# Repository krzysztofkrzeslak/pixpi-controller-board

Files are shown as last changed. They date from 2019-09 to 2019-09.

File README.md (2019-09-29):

### PiXPi controller board source

This are sources for PiXPi controller board

Morea bout project on: https://hackaday.io/project/166730-pixpi-dslr-camera-controller

<p align="center">
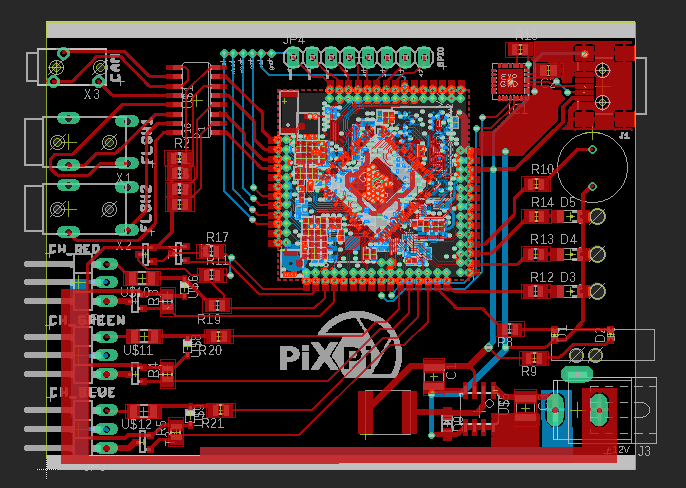
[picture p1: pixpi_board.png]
  
</p>

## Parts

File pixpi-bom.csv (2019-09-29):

Part | Value | Device | Package | Model
C1 | 47u | CC1210 | C1210
C2 | 100n | C | C0805
C3 | 22u | CC1210 | C1210
D1 | Blue | LEDCHIPLED_0603 | CHIPLED_0603 | FYLS-0603UBC
D2 | Green | LEDCHIPLED_0603 | CHIPLED_0603 | CL-197HG5-CF
D3 | Blue | LEDCHIPLED_1206 | CHIPLED_1206 | FYLS-1206UBC
D4 | Green | LEDCHIPLED_1206 | CHIPLED_1206 | FYLS-1206PGC
D5 | Red | LEDCHIPLED_1206 | CHIPLED_1206 | FYLS-1206URC
D9 |  | DIODE-SOD323-W | SOD323-W | BAS3010A03WE6327HTSA1
IC1 | CP2101 | CP2101 | MLP28
J1 | USB_MINI-B_SMT | USB_MINI-B_SMT | USB-MINIB
J3 |  | JACK-PLUG0 | SPC4077 | NINIGI PC-GK2.1
JP1 |  | PINHD-1X3/90 | 1X03/90 | FCI 76382-303LF
JP2 |  | PINHD-1X3/90 | 1X03/90 | FCI 76382-303LF
JP3 |  | PINHD-1X3/90 | 1X03/90 | FCI 76382-303LF
JP4 |  | PINHD-1X8 | 1X08
R1 | 470R | R-EU_R0805 | R0805
R2 | 470R | R-EU_R0805 | R0805
R3 | 100k | R-EU_R0805 | R0805
R4 | 100k | R-EU_R0805 | R0805
R5 | 100k | R-EU_R0805 | R0805
R6 | 470R | R-EU_R0805 | R0805
R7 | 470R | R-EU_R0805 | R0805
R8 | 10k | R-EU_R0805 | R0805
R9 | 10k | R-EU_R0805 | R0805
R10 | 10R | R-EU_R0805 | R0805
R11 | 4.7k | R-EU_R0805 | R0805
R12 | 470R | R-EU_R0805 | R0805
R13 | 1k | R-EU_R0805 | R0805
R14 | 470R | R-EU_R0805 | R0805
R15 | 4.7k | R-EU_R0805 | R0805
R17 | 100k | R-EU_R0805 | R0805
R19 | 220R | R-EU_R0805 | R0805
R20 | 220R | R-EU_R0805 | R0805
R21 | 220R | R-EU_R0805 | R0805
T1 |  | NMOSSOT23 | SOT-23 | TSM2312CX
T2 |  | NMOSSOT23 | SOT-23 | TSM2312CX
T3 |  | NMOSSOT23 | SOT-23 | TSM2312CX
T4 |  | NMOSSOT23 | SOT-23 | 2N7002
T5 |  | NMOSSOT23 | SOT-23 | 2N7002
U$1 | QUAD_OPTOCOUPLER | QUAD_OPTOCOUPLER | SO16 | TCMT4100
U$2 | VOCORE2 | VOCORE2 | VOCORE2
U$3 | LD-BZEG-0905 | LD-BZEG-0905 | LD-BZEG-0905 | LD-BZEG-0905
U$4 | 1X6 | 1X6 | 1X6
U$5 | AP1509 | AP1509 | SOP08
U$6 | BZX84J | BZX84J | SOD323_ST | BZX84J-B3V6.115
U$7 | 33uH | DJNR6028 | DJNR6028
U$8 | BZX84J | BZX84J | SOD323_ST | BZX84J-B3V6.115
U$9 | BZX84J | BZX84J | SOD323_ST | BZX84J-B3V6.115
U$10 | SN005 | SN005 | R1206 | ECE SN005-60
U$11 | SN005 | SN005 | R1206 | ECE SN005-60
U$12 | SN005 | SN005 | R1206 | ECE SN005-60
X1 | 1503_08 | 1503_08 | 1503_08
X2 | 1503_08 | 1503_08 | 1503_08 | LUMBERG 1503 08
X3 | 1501_03 | 1501_03 | 1501_03 | 1501-03

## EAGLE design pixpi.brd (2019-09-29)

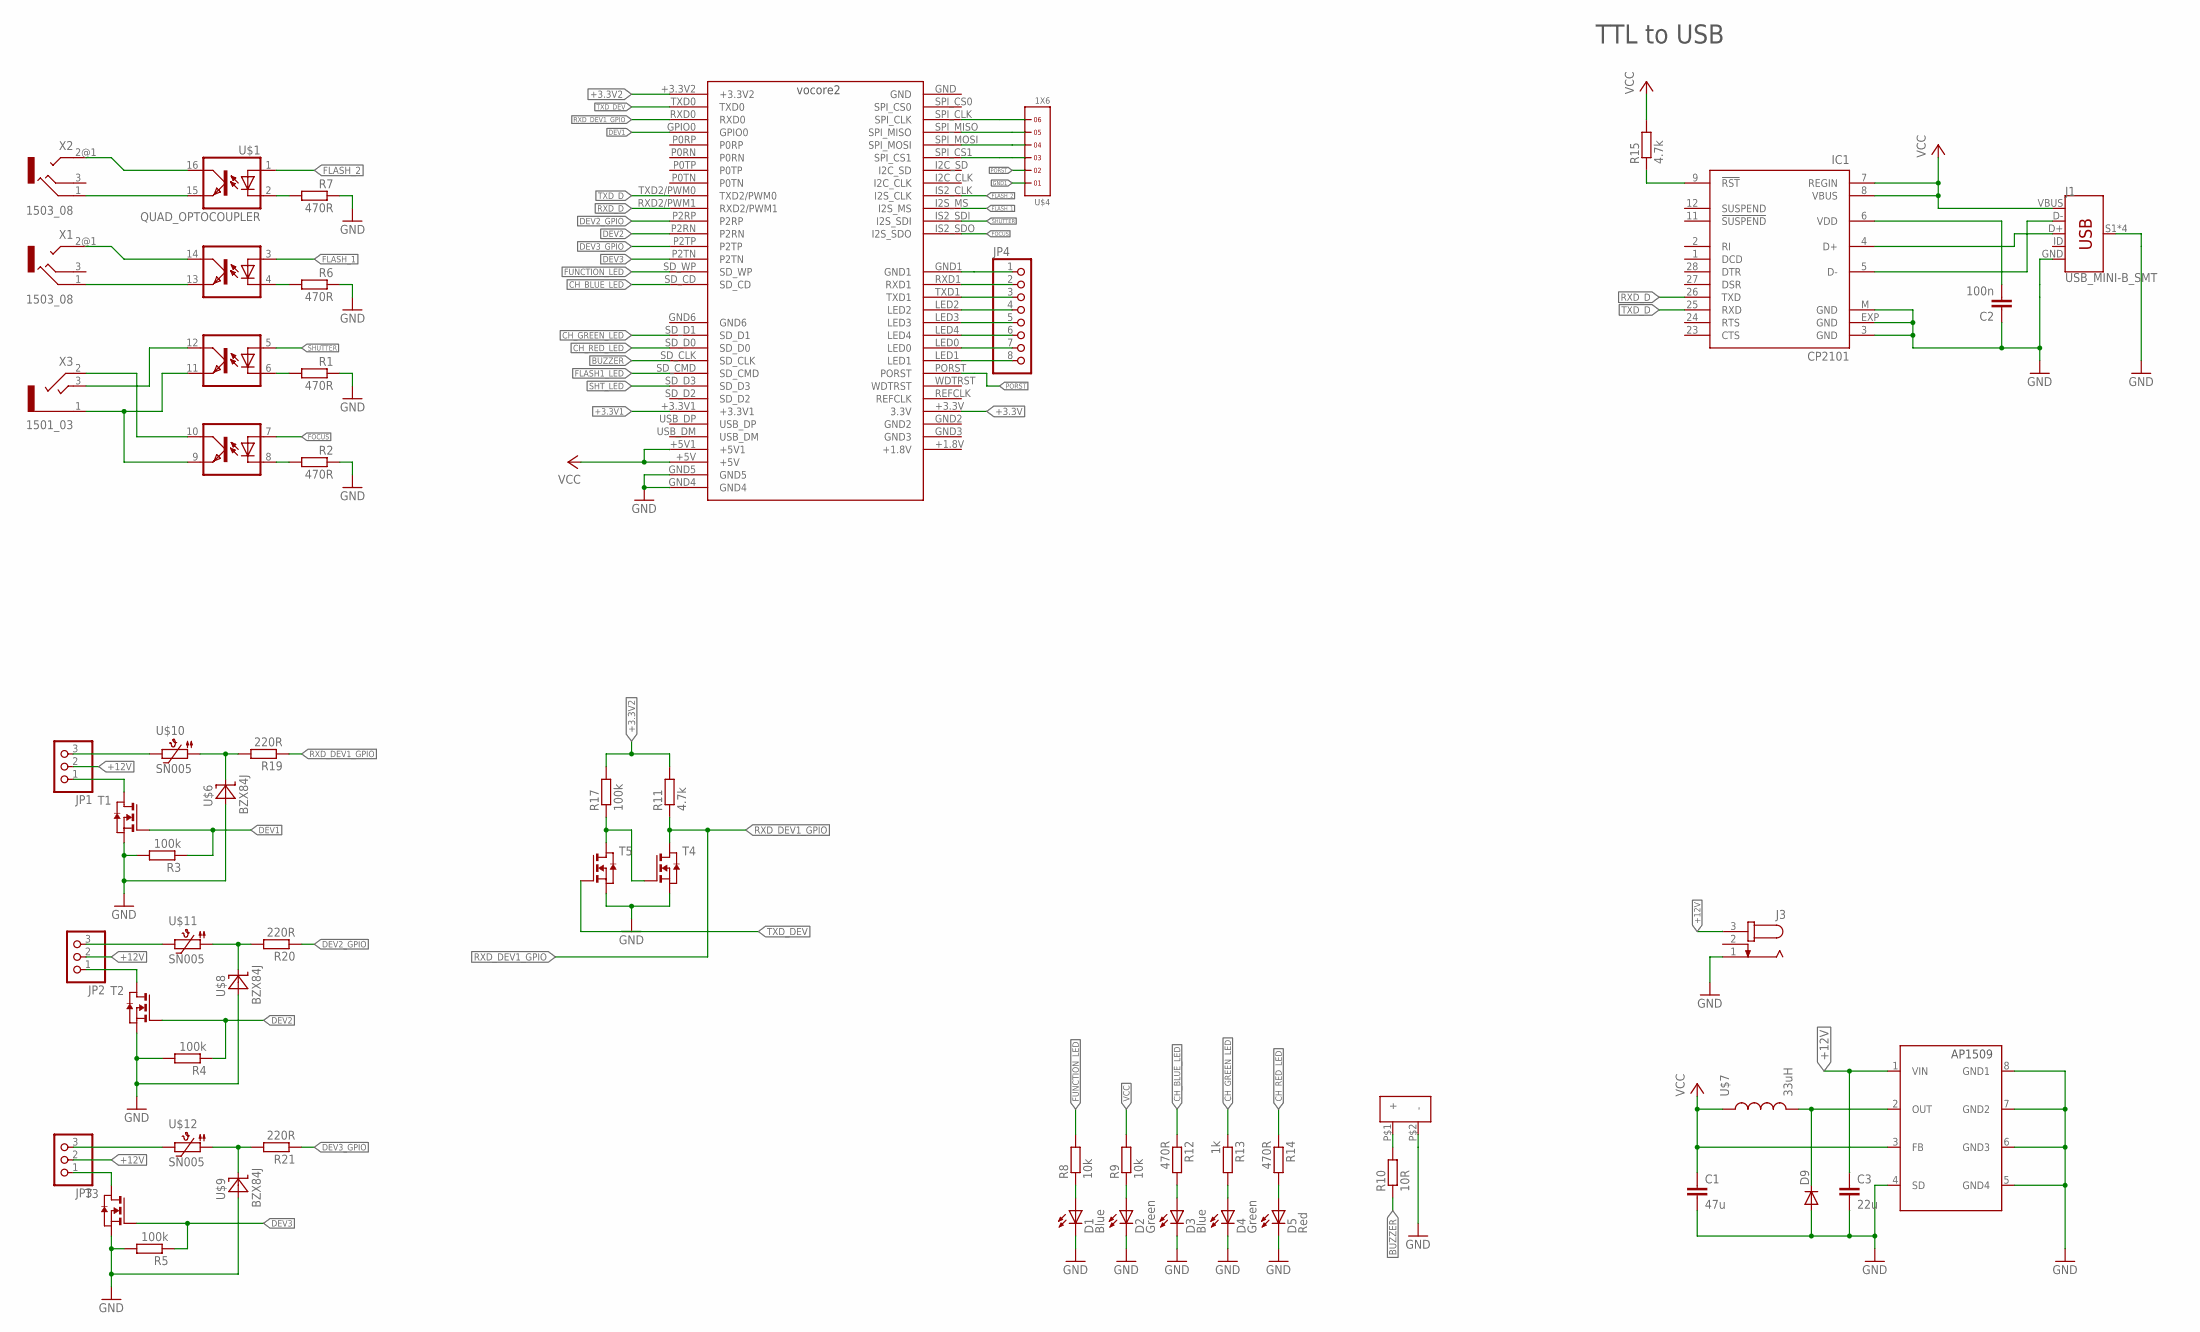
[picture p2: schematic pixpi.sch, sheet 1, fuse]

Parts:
C1: 47u; C1210
C2: 100n; C0805
C3: 22u; C1210
D1: Blue; CHIPLED_0603
D2: Green; CHIPLED_0603
D3: Blue; CHIPLED_1206
D4: Green; CHIPLED_1206
D5: Red; CHIPLED_1206
D9: DIODE-SOD323-W; SOD323-W
IC1: CP2101; MLP28
J1: USB_MINI-B_SMT; USB-MINIB
J3: JACK-PLUG0; SPC4077
JP1, JP2, JP3: PINHD-1X3/90; 1X03/90
JP4: PINHD-1X8; 1X08
R1, R2, R6, R7, R12, R14: 470R; R0805
R3, R4, R5, R17: 100k; R0805
R8, R9: 10k; R0805
R10: 10R; R0805
R11, R15: 4.7k; R0805
R13: 1k; R0805
R19, R20, R21: 220R; R0805
T1, T2, T3, T4, T5: NMOSSOT23; SOT-23
U$1: QUAD_OPTOCOUPLER; SO16
U$2: VOCORE2
U$3: LD-BZEG-0905
U$4: 1X6
U$5: AP1509; SOP08
U$6, U$8, U$9: BZX84J; SOD323_ST
U$7: 33uH; DJNR6028
U$10, U$11, U$12: SN005; R1206
X1, X2: 1503_08
X3: 1501_03

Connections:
+3.3V: U$2.+3.3V (3.3V)
+3.3V1: U$2.+3.3V1
+3.3V2: R11.2, R17.2, U$2.+3.3V2
+12V: C3.1, J3.3, JP1.2, JP2.2, JP3.2, U$5.1 (VIN)
BUZZER: R10.1, U$2.SD_CLK
CH_BLUE_LED: R12.1, U$2.SD_CD
CH_GREEN_LED: R13.1, U$2.SD_D1
CH_RED_LED: R14.1, U$2.SD_D0
DEV1: R3.1, T1.3 (G), U$2.GPIO0
DEV2: R4.1, T2.3 (G), U$2.P2RN
DEV2_GPIO: R20.1, U$2.P2RP
DEV3: R5.1, T3.3 (G), U$2.P2TN
DEV3_GPIO: R21.1, U$2.P2TP
FLASH1_LED: U$2.SD_CMD
FLASH_1: U$1.3 (A1), U$2.I2S_MS
FLASH_2: U$1.1 (A), U$2.IS2_CLK (I2S_CLK)
FOCUS: U$1.7 (A3), U$2.IS2_SDO (I2S_SDO)
FUNCTION_LED: R8.2, U$2.SD_WP
GND: C1.2, C2.1, C3.2, D1.C, D2.C, D3.C, D4.C, D5.C, D9.A, IC1.3 (GND), IC1.EXP (GND), IC1.M (GND), J1.GND, J1.S1 (SHIELD), J1.S2 (SHIELD), J1.S3 (SHIELD), J1.S4 (SHIELD), J3.1, R1.1, R2.1, R3.2, R4.2, R5.2, R6.1, R7.1, T1.2 (S), T2.2 (S), T3.2 (S), T4.2 (S), T5.2 (S), U$2.GND4, U$2.GND5, U$3.P$2 (-), U$5.4 (SD), U$5.5 (GND4), U$5.6 (GND3), U$5.7 (GND2), U$5.8 (GND1), U$6.A, U$8.A, U$9.A
GND1: JP4.1, U$2.GND1, U$4.1
unnamed: JP2.1, T2.1 (D)
unnamed: R19.2, U$6.C, U$10.1
unnamed: D9.C, U$5.2 (OUT), U$7.P$4 (2)
unnamed: U$1.13 (EMIT1), X1.1
unnamed: U$1.10 (COL3), X3.2
unnamed: JP1.3, U$10.2
unnamed: R6.2, U$1.4 (C1)
unnamed: JP3.1, T3.1 (D)
unnamed: R21.2, U$9.C, U$12.1
unnamed: U$1.12 (COL2), X3.3
unnamed: U$1.9 (EMIT3), U$1.11 (EMIT2), X3.1
unnamed: R1.2, U$1.6 (C2)
unnamed: R10.2, U$3.P$1 (+)
unnamed: R2.2, U$1.8 (C3)
unnamed: JP2.3, U$11.2
unnamed: U$1.14 (COL1), X1.2@1 (2)
unnamed: JP3.3, U$12.2
unnamed: D2.A, R9.1
unnamed: D1.A, R8.1
unnamed: R20.2, U$8.C, U$11.1
unnamed: JP1.1, T1.1 (D)
unnamed: IC1.9 (!RST), R15.1
unnamed: U$2.SPI_CS1, U$4.3
unnamed: IC1.5 (D-), J1.D-
unnamed: IC1.4 (D+), J1.D+
unnamed: C2.2, IC1.6 (VDD)
unnamed: U$2.SPI_MOSI, U$4.4
unnamed: U$2.SPI_MISO, U$4.5
unnamed: U$2.SPI_CLK, U$4.6
unnamed: R17.1, T4.3 (G), T5.1 (D)
unnamed: D3.A, R12.2
unnamed: D4.A, R13.2
unnamed: U$1.15 (EMIT), X2.1
unnamed: U$1.16 (COL), X2.2@1 (2)
unnamed: D5.A, R14.2
unnamed: R7.2, U$1.2 (C)
unnamed: JP4.2, U$2.RXD1
unnamed: JP4.3, U$2.TXD1
unnamed: JP4.4, U$2.LED2
unnamed: JP4.5, U$2.LED3
unnamed: JP4.6, U$2.LED4
unnamed: JP4.7, U$2.LED0
unnamed: JP4.8, U$2.LED1
PORST: U$2.PORST, U$4.2
RXD_D: IC1.26 (TXD), U$2.RXD2/PWM1
RXD_DEV1_GPIO: R11.1, R19.1, T4.1 (D), U$2.RXD0
SHT_LED: U$2.SD_D3
SHUTTER: U$1.5 (A2), U$2.IS2_SDI (I2S_SDI)
TXD_D: IC1.25 (RXD), U$2.TXD2/PWM0
TXD_DEV: T5.3 (G), U$2.TXD0
VCC: C1.1, IC1.7 (REGIN), IC1.8 (VBUS), J1.VBUS, R9.2, R15.2, U$2.+5V, U$2.+5V1, U$5.3 (FB), U$7.P$3 (1)

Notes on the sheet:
TTL to USB

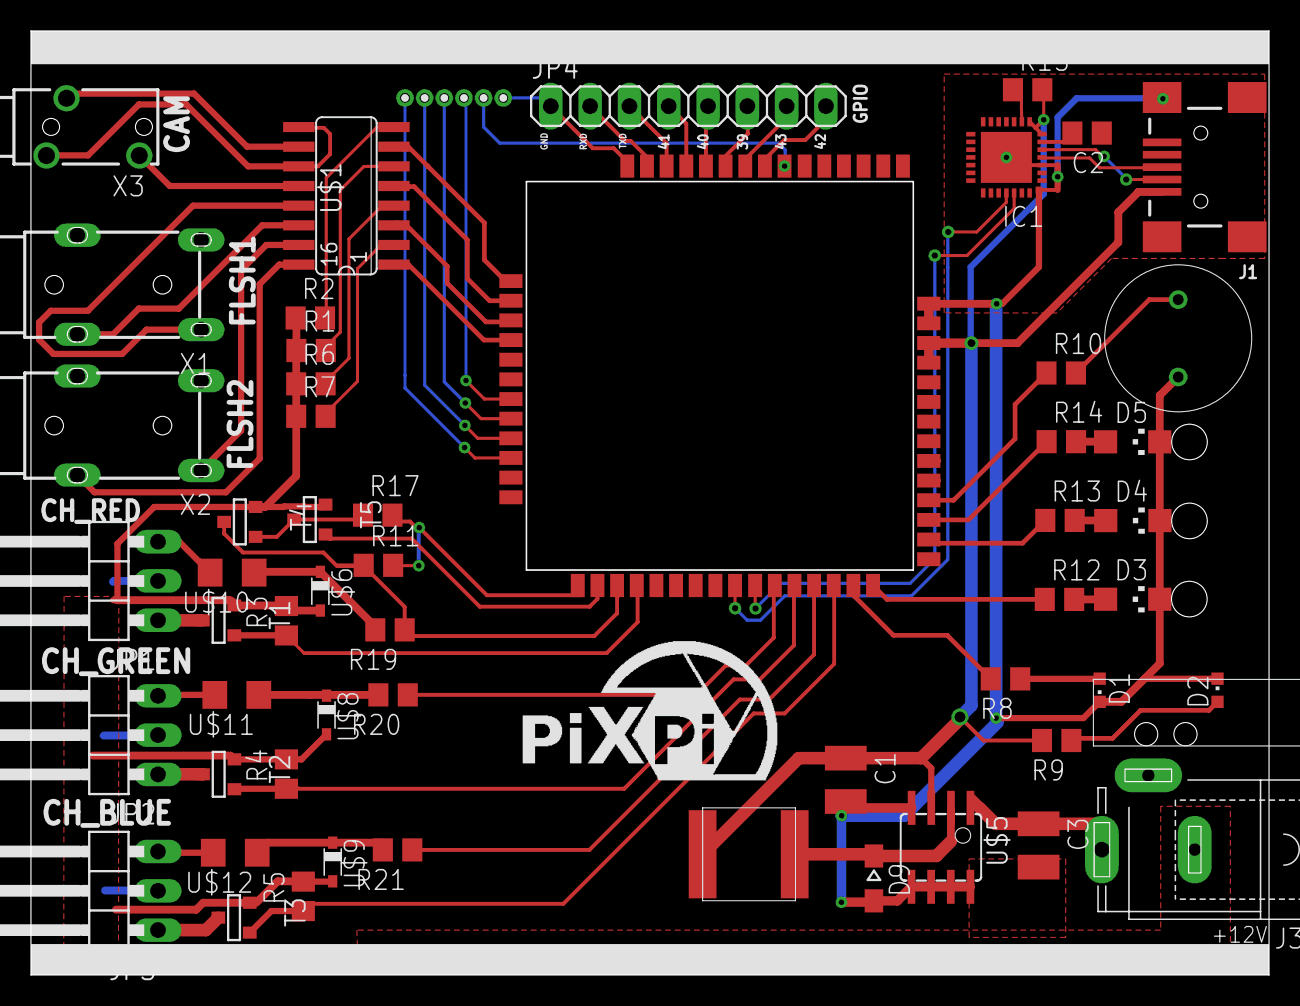
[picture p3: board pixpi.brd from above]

Board: 2 copper layers, 80.0 x 61.0 mm, 55 parts (0 on the bottom side), 67 nets.

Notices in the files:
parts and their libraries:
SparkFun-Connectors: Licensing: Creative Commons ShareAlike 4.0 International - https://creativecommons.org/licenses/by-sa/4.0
